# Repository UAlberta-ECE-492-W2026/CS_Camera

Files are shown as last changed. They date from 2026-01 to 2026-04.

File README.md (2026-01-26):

# Compressed Sensing Camera

## Project Overview
The objective of this capstone project is to design and build a functional prototype camera using compressed sensing principles with a single-pixel sensor to capture visible light. The system will acquire compressed measurements and reconstruct images using computational algorithms, demonstrating the viability of sub-Nyquist sampling for image acquisition.

## Team Members
- **[Mazen]** - [Role/Responsibility]
- **[Omar]** - [Role/Responsibility]
- **[Cole]** - [Role/Responsibility]
- **[Ghassan]** - [Role/Responsibility]

**Supervisor:** Steven Knudsen 
**Course:** ECE 492 - Capstone Design Project  
**Institution:** University of Alberta  
**Term:** Winter 2026

## Project Goals
- Design and implement hardware for single-pixel compressed sensing camera
- Develop firmware for measurement acquisition and control
- Implement image reconstruction algorithms (e.g., basis pursuit, greedy algorithms)
- Validate system performance through experimental testing
- Deliver a working prototype with documentation

## System Architecture
The system consists of three main components:
1. **Optical Frontend** - Single-pixel detector, spatial light modulator/DMD, optics
2. **Embedded System** - Microcontroller-based data acquisition and control
3. **Reconstruction Backend** - PC-based image processing and reconstruction

## Repository Structure
```
CS_Camera/
├── Firmware/              # Embedded firmware for sensor control and data acquisition
├── Image_reconstruction/  # Image reconstruction algorithms and processing code
├── docs/                  # Design documents, reports, and presentations
├── hardware/             # Schematics, PCB files, and hardware documentation
├── tests/                # Test scripts and validation data
├── data/                 # Sample measurements and calibration files
└── README.md             # This file
```

## Getting Started

### Prerequisites
**Hardware:**
- 
- Development board: Pi 
- Single-pixel detector: 
- LCD:

**Software:**
- TODO

### Installation
```bash
# Clone the repository
git clone git@github.com:UAlberta-ECE-492-W2026/CS_Camera.git
cd CS_Camera

# Setup firmware development environment
cd Firmware

```

### Quick Start
TODO

## Development Workflow
- **Branch Strategy:** Feature branches off `main`, merge via pull requests
- **Code Review:** All PRs require at least two review before merging
- **Testing:** Run tests before committing changes
- **Documentation:** Update relevant docs with any architectural changes

## Documentation

- Design specifications
- Hardware schematics
- Algorithm descriptions
- Testing procedures
- Final report and presentations

## Current Status/Milestones
- [ ] Project planning and requirements definition
- [ ] Hardware design and component selection
- [ ] Firmware development
- [ ] Image reconstruction algorithm implementation
- [ ] System integration and testing
- [ ] Final documentation and presentation

**Last Updated:** January 26, 2026

## Acknowledgments
Special thanks to the University of Alberta ECE Department and our project supervisor for their support and guidance.

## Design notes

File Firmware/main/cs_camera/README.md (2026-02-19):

# CS Camera - Modular Firmware Structure

## Project Structure

```
Firmware/main/
├── main.c                       # Main entry point
├── CMakeLists.txt              # Root build configuration
├── pico_sdk_import.cmake       # Pico SDK import
│
├── modules/
│   ├── storage/                # SD Card Module
│   │   ├── sd_storage.h        # Storage API
│   │   ├── sd_storage.c        # Storage implementation
│   │   ├── hw_config.h         # SD card hardware config
│   │   ├── hw_config.c
│   │   └── CMakeLists.txt      # Builds 'storage' library
│   │
│   ├── sensor/                 # Photodiode/ADC Module
│   │   ├── photodiode.h        # Sensor API
│   │   ├── photodiode.c        # Sensor implementation
│   │   └── CMakeLists.txt      # Builds 'sensor' library
│   │
│   └── display/                # LCD Display Module
│       ├── lcd_driver.h        # Display API
│       ├── lcd_driver.c        # Display implementation (stub)
│       └── CMakeLists.txt      # Builds 'display' library
│
└── ../lib/
    └── no-OS-FatFS/            # External FatFS library (shared)
```

## How It Works

### Single Project, Multiple Modules
- **One** Pico project with **one** root `CMakeLists.txt`
- Each module is a **library** (not a separate project)
- All modules compile together into **one** `.uf2` file

### Module Independence
- **Storage**: Handles SD card, file system, data logging
- **Sensor**: Handles photodiode ADC sampling
- **Display**: Handles LCD graphics and rendering
- **Main**: Coordinates all modules, implements application logic

### Clean Interfaces
Each module exposes a simple API:
- `module_init()` - Initialize the module
- `module_*()` - Module-specific functions
- Modules don't depend on each other

## Building the Project

### Using VS Code Pico Extension

1. **Open the main folder** in VS Code:
   - File → Open Folder → Select `Firmware/main/`

2. **Configure the project**:
   - Pico extension should detect the project automatically
   - Select Pico2 board if prompted

3. **Compile**:
   - Click "Compile" in the Pico extension
   - Or use CMake Tools extension

4. **Flash to Pico**:
   - Hold BOOTSEL button, connect Pico
   - Copy `build/cs_camera.uf2` to the Pico drive

### Manual Build

```bash
cd Firmware/main
mkdir build
cd build
cmake ..
make
```

## Module APIs

### Storage Module
```c
#include "modules/storage/sd_storage.h"

bool storage_init(void);
int storage_write_file(const char *filename, const void *data, uint32_t size);
int storage_append_file(const char *filename, const void *data, uint32_t size);
```

### Sensor Module
```c
#include "modules/sensor/photodiode.h"

bool sensor_init(void);
uint16_t sensor_read_sample(void);
uint16_t sensor_read_voltage_mv(void);
```

### Display Module
```c
#include "modules/display/lcd_driver.h"

bool display_init(void);
void display_clear(uint16_t color);
void display_text(uint16_t x, uint16_t y, const char *text, uint16_t color);
```

## Next Steps

### Display Module
The display module is currently a **stub**. To implement:
1. Determine your LCD type (ST7735, ILI9341, etc.)
2. Add LCD driver library or implement SPI communication
3. Update `lcd_driver.c` with actual initialization and drawing

### Sensor Module
- Currently implements basic ADC reading
- TODO: Add DMA-based continuous sampling
- TODO: Add data buffering for high-speed acquisition

### Storage Module
- Fully functional for basic file operations
- Tested with FatFS library
- Ready for data logging

## Pin Configuration

### SD Card (SPI1)
- GPIO 10: SCK
- GPIO 11: MOSI
- GPIO 12: MISO
- GPIO 13: CS

### Photodiode
- GPIO 26: ADC0 (Analog input)

### LCD (To be configured)
- TBD based on your LCD module

## Adding New Modules

1. Create folder: `modules/new_module/`
2. Create files: `new_module.h`, `new_module.c`, `CMakeLists.txt`
3. In module `CMakeLists.txt`:
   ```cmake
   add_library(new_module STATIC new_module.c)
   target_include_directories(new_module PUBLIC ${CMAKE_CURRENT_LIST_DIR})
   target_link_libraries(new_module pico_stdlib)
   ```
4. In root `CMakeLists.txt`:
   ```cmake
   add_subdirectory(modules/new_module)
   target_link_libraries(cs_camera new_module)
   ```

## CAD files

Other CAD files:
hardware/Fusion/Lens D-Cx Dia38mm FL50mm.f3d
hardware/Fusion/SD Card Reader (Assembly).f3z

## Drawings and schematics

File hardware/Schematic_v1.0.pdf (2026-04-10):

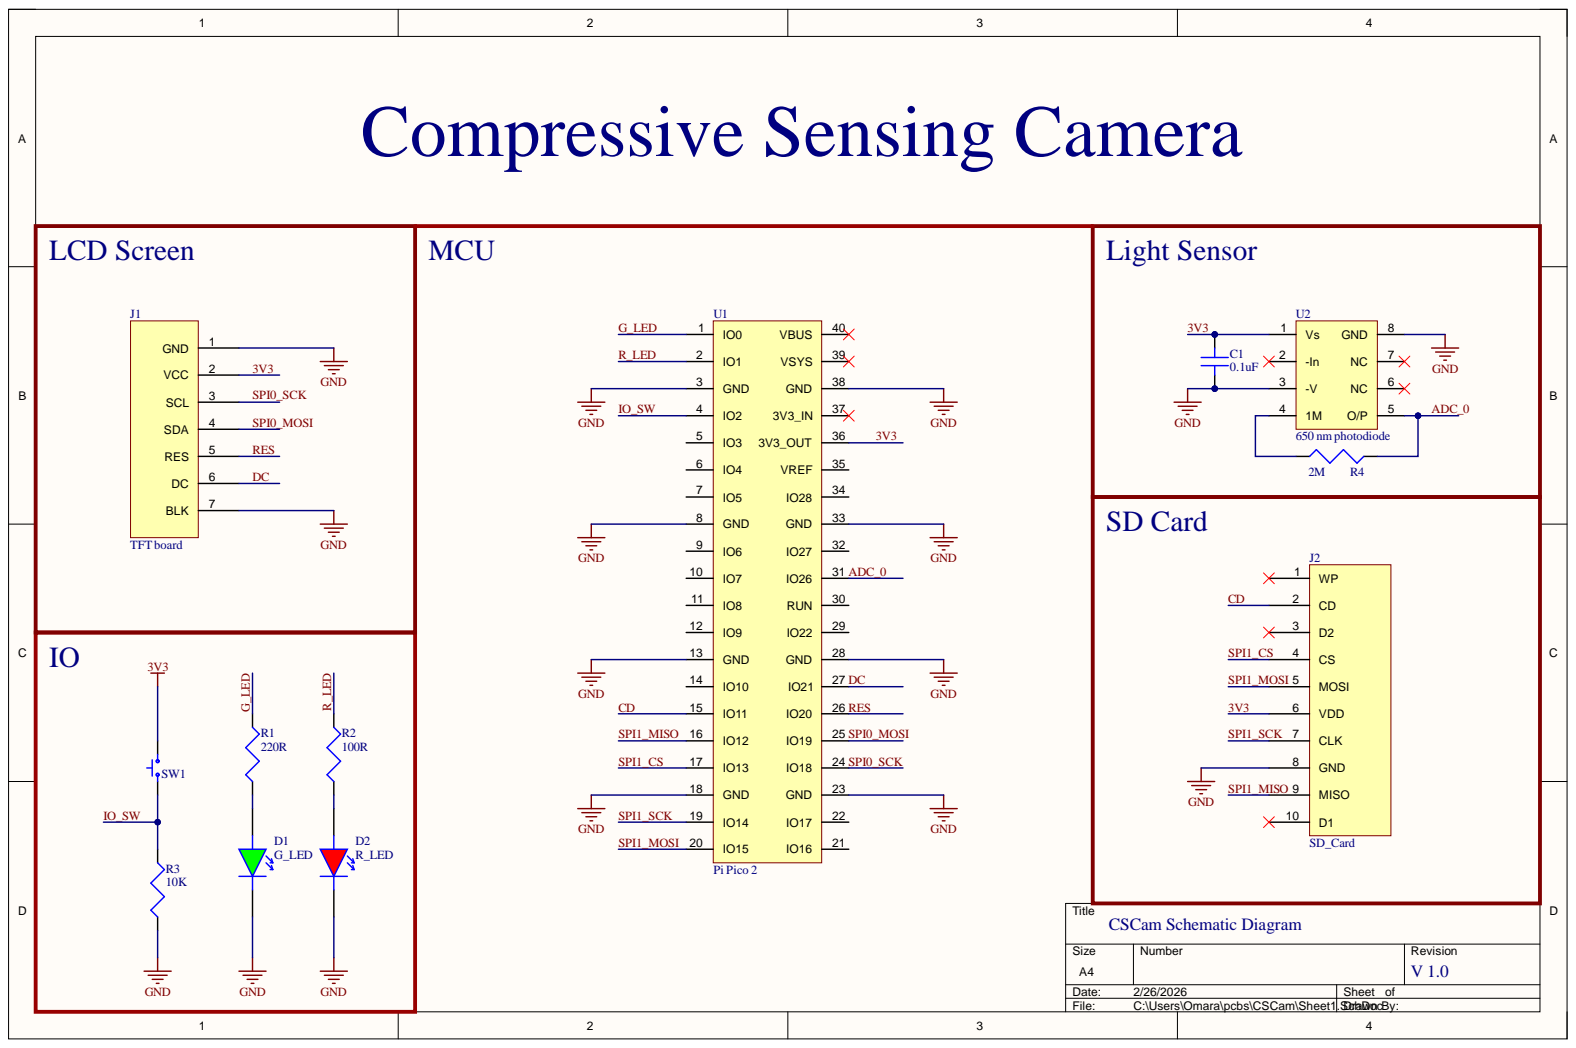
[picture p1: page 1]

S i z e A 4 | Number | Rev i s i o n V 1.0

Date: 2/26/2026 | Sheet of
F i le: C:\User s\Omara\pcbs\CSCam\Sheet1.SDrchDoc awn B | y :

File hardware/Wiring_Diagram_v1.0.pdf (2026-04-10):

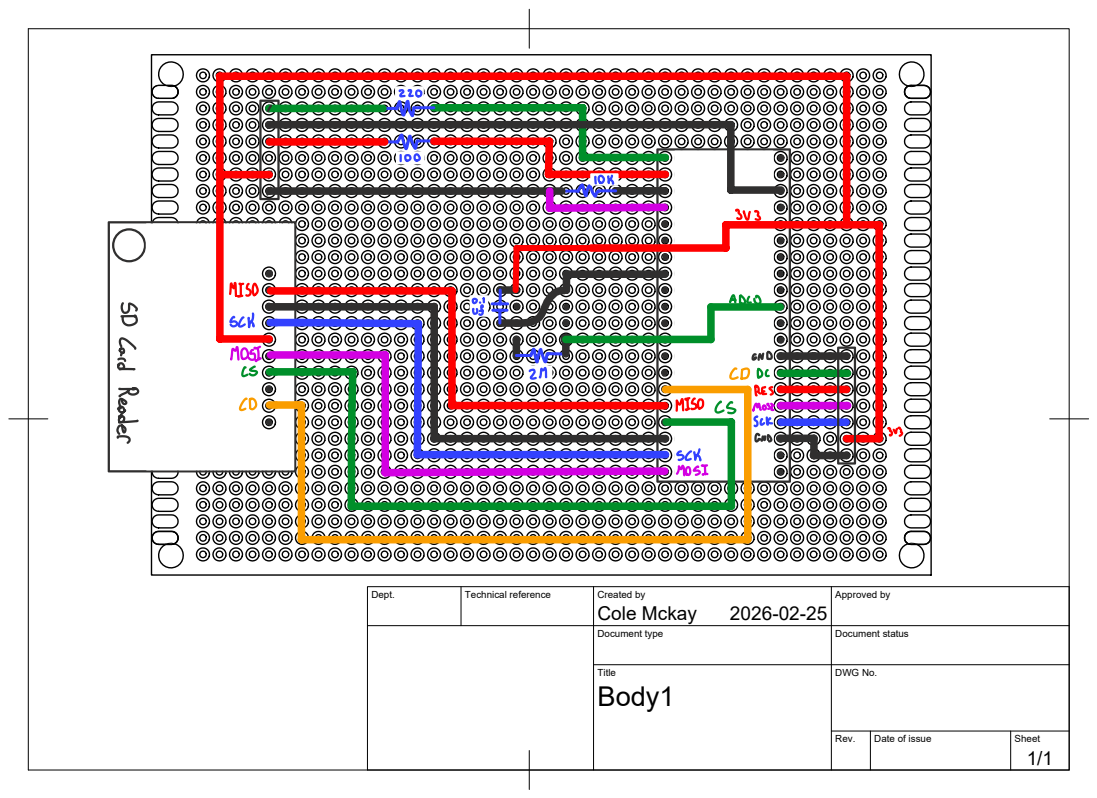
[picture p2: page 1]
Dept.; Technical reference; Created by; Approved by; Document type; Document status; Title; DWG No.; Rev.; Date of issue; Sheet; Body1; Cole Mckay

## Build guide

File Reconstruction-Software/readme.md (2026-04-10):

# Compressive Sensing Camera — MATLAB Reconstruction Software

**Author:** Cole Mckay (cdmckay1@ualberta.ca)  
**Capstone Project — University of Alberta**

---

## Table of Contents

1. [Project Overview](#1-project-overview)
2. [Repository Structure](#2-repository-structure)
3. [Mathematical Background](#3-mathematical-background)
   - [3.1 Walsh-Hadamard Basis & Compressive Sensing](#31-walsh-hadamard-basis--compressive-sensing)
   - [3.2 Simple Back-Projection Reconstruction](#32-simple-back-projection-reconstruction)
   - [3.3 Edge-Preserving Total Variation Reconstruction](#33-edge-preserving-total-variation-reconstruction)
4. [CNN Enhancement Architecture](#4-cnn-enhancement-architecture)
   - [4.1 Motivation](#41-motivation)
   - [4.2 Network Architecture (ResNet-style)](#42-network-architecture-resnet-style)
   - [4.3 Training Pipeline](#43-training-pipeline)
5. [Camera Emulation](#5-camera-emulation)
6. [MATLAB Apps](#6-matlab-apps)
7. [Configuration](#7-configuration)
8. [Getting Started](#8-getting-started)
9. [Dependencies](#9-dependencies)

---

## 1. Project Overview

This repository folder contains the MATLAB software layer for a **single-pixel compressive sensing (CS) camera** capstone project. Rather than capturing a full image on a conventional sensor array, the hardware captures a scene through a sequence of structured **Walsh-Hadamard binary masks** and records a single scalar measurement (ADC value) per mask. The software then reconstructs a full 2D image from this heavily undersampled measurement set using one of three algorithms:

| Algorithm | Speed | Quality | Notes |
|---|---|---|---|
| Simple Back-Projection | Fast | Moderate | Linear; good baseline |
| Total Variation (TV) | Slow | High | Edge-preserving, iterative |
| CNN Enhancement | Fast (inference) | Highest | Requires pre-trained model |

---

## 2. Repository Structure

```
project_root/
│
├── +reco/                          # Reconstruction algorithms
│   ├── simpleReconstruction.m      # Linear back-projection
│   ├── tvReconstruction.m          # TV-minimization solver
│   └── cnnReconstruction.m         # CNN-enhanced reconstruction
│
├── +utils/                         # Core utility functions
│   ├── emulateCameraCapture.m      # Hardware emulation
│   ├── generateWalshMask.m         # Walsh-Hadamard mask generation
│   ├── getOptimalCore.m            # Optimal low-frequency mask selection
│   ├── loadConfig.m                # JSON config loader
│   ├── selectMaskIndexes.m         # Sampling strategy selector
│   └── simulateCapture.m          # ADC capture simulation
│
├── +models/                        # Trained CNN model files (.mat)
│   ├── cs_enhancement_net_ResNet.mat
│   └── cs_enhancement_net_ResNet_50p.mat
│
├── +tools/                         # Standalone scripts & tools
│   ├── train_CS_Enhancement_CNN.m  # CNN training script
│   ├── test_emulateCameraCapture.m # Integration test
│   ├── generate_training_data.m    # Dataset generation
│   └── ...
│
├── configs/
│   └── camera_settings.json        # Resolution, sampling %, noise params
│
├── data/                           # Training datasets and capture CSVs
├── images/                         # Test images (BSDS300, tiny-imagenet)
├── mask_firmware/                  # Embedded C++ mask generator for hardware
│   ├── main.cpp
│   ├── WalshMaskGenerator.cpp
│   └── WalshMaskGenerator.h
│
├── assets/
│   └── eng_logo.png
│
├── Emulation_app.mlapp             # MATLAB App: camera emulation UI
└── Reconstruction_app.mlapp        # MATLAB App: reconstruction UI
```

---

## 3. Mathematical Background

### 3.1 Walsh-Hadamard Basis & Compressive Sensing

The system measures a scene $\mathbf{x} \in \mathbb{R}^{N}$ (a vectorized $\sqrt{N} \times \sqrt{N}$ image) using $M \ll N$ linear measurements. Each measurement $y_i$ is the inner product of the scene with a binary Walsh-Hadamard mask $\mathbf{\phi}_i \in \{0, 1\}^N$:

$$y_i = \mathbf{\phi}_i^T \mathbf{x} + \eta_i, \quad i = 1, \ldots, M$$

where $\eta_i$ is additive noise. Stacking all measurements:

$$\mathbf{y} = \mathbf{\Phi} \mathbf{x} + \mathbf{\eta}$$

where $\mathbf{\Phi} \in \mathbb{R}^{M \times N}$ is the **sensing matrix**, with each row being a flattened Walsh mask. Because Walsh-Hadamard functions form an orthonormal basis ordered by **sequency** (the number of zero-crossings, analogous to frequency), the system preferentially captures low-sequency masks — which carry the most image energy — enabling meaningful reconstruction even at aggressive undersampling ratios (e.g., 50%).

A DC baseline is removed before reconstruction to center the measurements:

$$\mathbf{y}_{AC} = \mathbf{y} - \bar{y}\mathbf{1}$$

---

### 3.2 Simple Back-Projection Reconstruction

The simplest reconstruction is a **linear back-projection** (pseudo-inverse approximation):

$$\hat{\mathbf{x}} = \mathbf{\Phi}^T \mathbf{y}_{AC}$$

In practice, this is computed mask-by-mask without explicitly forming $\mathbf{\Phi}$:

$$\hat{\mathbf{x}} = \sum_{i=1}^{M} y_{AC,i} \cdot \mathbf{\phi}_i$$

Each Walsh mask is weighted by its AC measurement value and accumulated into the image. The result is normalized to $[0, 1]$:

$$\hat{x}_{norm} = \frac{\hat{\mathbf{x}} - \min(\hat{\mathbf{x}})}{\max(\hat{\mathbf{x}}) - \min(\hat{\mathbf{x}})}$$

**Complexity:** $O(M \cdot N)$ — fast, but produces visible Walsh-Hadamard ringing artifacts at low sampling rates because the unmeasured basis components implicitly contribute zero energy.

> **Implemented in:** `+reco/simpleReconstruction.m`

---

### 3.3 Edge-Preserving Total Variation Reconstruction

To suppress ringing artifacts while preserving sharp edges, the system solves a **Total Variation (TV) minimization** problem:

$$\hat{\mathbf{x}} = \arg\min_{\mathbf{x}} \underbrace{\|\mathbf{\Phi}\mathbf{x} - \mathbf{y}\|_2^2}_{\text{data fidelity}} + \lambda \underbrace{\text{TV}_w(\mathbf{x})}_{\text{regularization}}$$

where $\lambda$ is a regularization weight (set to 50 in the current configuration).

#### Isotropic TV with Perona-Malik Edge Weighting

Standard isotropic TV uses the image gradient magnitude:

$$\text{TV}(\mathbf{x}) = \sum_{p} \sqrt{(\nabla_x \mathbf{x}_p)^2 + (\nabla_y \mathbf{x}_p)^2}$$

This implementation extends TV with **Perona-Malik edge weights** $w_p$ to be less penalizing at strong edges:

$$w_p = \frac{1}{1 + \left(\|\nabla \mathbf{x}_p\| / \sigma\right)^2}$$

where $\sigma$ is an adaptive edge-stopping threshold set to $0.25 \cdot \max(|\mathbf{y}|)$. The weighted TV gradient (used in the gradient descent update) becomes the divergence of the weighted normalized gradient field:

$$\nabla_\mathbf{x} \text{TV}_w = -\text{div}\left( w_p \cdot \frac{\nabla \mathbf{x}}{\|\nabla \mathbf{x}\| + \epsilon} \right)$$

where $\epsilon = 10^{-5}$ prevents division by zero.

#### Gradient Descent Solver

The full gradient descent update at iteration $k$ is:

$$\mathbf{x}^{(k+1)} = \mathbf{x}^{(k)} - \alpha \left[ \mathbf{\Phi}^T(\mathbf{\Phi}\mathbf{x}^{(k)} - \mathbf{y}) + \lambda \nabla_\mathbf{x} \text{TV}_w(\mathbf{x}^{(k)}) \right]$$

The step size $\alpha$ is set using the **Lipschitz-stable** rule:

$$\alpha = \frac{1.9}{\|\mathbf{\Phi}\|_2^2}$$

The solver runs for 300 iterations, printing progress every 50. The initial state is seeded with the linear back-projection $\mathbf{x}^{(0)} = \mathbf{\Phi}^T \mathbf{y}_{AC}$.

> **Implemented in:** `+reco/tvReconstruction.m`

---

## 4. CNN Enhancement Architecture

### 4.1 Motivation

The simple back-projection reconstruction is fast but suffers from structured **Walsh-Hadamard artifacts** — a characteristic checkerboard-like pattern caused by the abrupt truncation of the measurement basis. Rather than solving an expensive iterative optimization at inference time, a **residual convolutional neural network** learns a mapping from the noisy back-projection to the ground-truth image, effectively learning to suppress exactly the artifact pattern produced by this sensing system.

### 4.2 Network Architecture (ResNet-style)

The network is a lightweight **residual (skip-connection) CNN** that learns the *artifact residual* rather than the full image mapping. This is motivated by the observation that the back-projection $\hat{\mathbf{x}}$ already contains the correct low-frequency image content — only the high-frequency artifact component needs to be estimated and removed.

```
Input (N×N×1)
    │
    ├────────────────────────────────── Skip Connection ──────────────────────┐
    │                                                                          │
    ▼                                                                          │
Conv2D (5×5, 64 filters) → ReLU                  ← Artifact extraction       │
    ▼                                                                          │
Conv2D (3×3, 32 filters) → ReLU                  ← Artifact refinement       │
    ▼                                                                          │
Conv2D (5×5, 1 filter)                            ← Artifact map              │
    │                                                                          │
    └───────────────────────────────────► Addition ◄──────────────────────────┘
                                              │
                                              ▼
                                    Enhanced Output (N×N×1)
                                              │
                                              ▼
                                    Regression Loss (MSE)
```

The network learns artifact weights $\mathbf{r}$ such that:

$$\hat{\mathbf{x}}_{enhanced} = \hat{\mathbf{x}}_{simple} + f_{CNN}(\hat{\mathbf{x}}_{simple}; \mathbf{\theta})$$

where $f_{CNN}$ is the residual branch. At inference, this is equivalent to the network predicting the ground truth directly via the identity shortcut.

**Layer details:**

| Layer | Kernel | Filters | Activation | Role |
|---|---|---|---|---|
| Conv1 | 5×5 | 64 | ReLU | Patch feature extraction |
| Conv2 | 3×3 | 32 | ReLU | Non-linear mapping |
| Conv3 | 5×5 | 1 | — | Residual artifact map |
| Addition | — | — | — | Skip + residual |

All convolutions use `'same'` padding to preserve spatial dimensions throughout.

### 4.3 Training Pipeline

> **Script:** `+tools/train_CS_Enhancement_CNN.m`

**Data Preparation:**

1. Raw ADC measurements $\mathbf{y}$ are loaded from `cnn_training_data_50p.mat`
2. The sensing matrix $\mathbf{\Phi}$ is built from the mask list
3. For each training sample, a simple back-projection is computed and normalized to produce $\hat{\mathbf{x}}^{(i)}_{simple}$ — this is the **network input**
4. The ground-truth cropped/resized image is the **network target**

**Training Configuration:**

| Parameter | Value |
|---|---|
| Optimizer | Adam |
| Initial Learning Rate | $10^{-3}$ |
| Max Epochs | 50 |
| Mini-batch Size | 64 |
| Shuffle | Every epoch |
| Execution | GPU (CUDA) |
| Loss | MSE (Regression) |
| Training Data | BSDS300 + tiny-imagenet @ 50% sampling |

**Trained model output:** `+models/cs_enhancement_net_ResNet_50p.mat`

The model is loaded **once** at first call using a `persistent` variable in `cnnReconstruction.m` to avoid repeated disk reads during a session.

---

## 5. Camera Emulation

> **Function:** `+utils/emulateCameraCapture.m`

The emulation pipeline mirrors the physical hardware capture process:

1. **Load image** — accepts a filepath or raw matrix
2. **Greyscale conversion** — colour images are converted via `im2gray`
3. **Square crop** — a centred square crop is taken using `centerCropWindow2d` to match the aspect ratio of the hardware aperture
4. **Resize** — the crop is resized to the target resolution defined in `camera_settings.json`
5. **Simulate capture** — `utils.simulateCapture` projects the image through each Walsh mask, optionally adding noise to emulate ADC quantization and photon shot noise

**Output format:** an $N \times 2$ matrix where column 1 is the mask index and column 2 is the ADC value. A header row with index $-1$ encodes the image resolution for downstream parsers.

---

## 6. MATLAB Apps

Two MATLAB App Designer GUIs are provided:

| App | File | Purpose |
|---|---|---|
| **Emulation App** | `Emulation_app.mlapp` | Load an image, select sampling %, run emulated capture, export data |
| **Reconstruction App** | `Reconstruction_app.mlapp` | Import capture CSV, choose reconstruction algorithm, display result |

---

## 7. Configuration

All camera and sampling parameters are stored in `configs/camera_settings.json`:

```json
{
    "hardware": {
        "adc_bits": 12,
        "v_ref": 3.3,
        "quantization_levels": 4096,
        "saturation_limit": 3800
    },
    "sampling_parameters": {
        "resolution": [64, 64],
        "samples_per_mask": 256,
        "sampling_pct": 0.25,
        "core_mask_count": 1024
    },
    "bias_profile": {
        "low_freq_bias_pct": 0.15
    },
    "sensor_noise": {
        "std_dev_counts": 2.5,
        "dark_current_counts": 12.0
    },
    "mask_constraints": {
        "black_leakage_pct": 0.01,
        "white_attenuation_pct": 1.0
    }
}
```

**Hardware**

| Field | Value | Description |
|---|---|---|
| `adc_bits` | 12 | ADC resolution |
| `v_ref` | 3.3 V | ADC reference voltage |
| `quantization_levels` | 4096 | Total ADC levels ($2^{12}$) |
| `saturation_limit` | 3800 | Clipping threshold (counts) |

**Sampling Parameters**

| Field | Value | Description |
|---|---|---|
| `resolution` | `[64, 64]` | Square image dimensions |
| `samples_per_mask` | 256 | ADC readings averaged per mask exposure |
| `sampling_pct` | 0.25 | Fraction of $N^2$ masks captured (25%) |
| `core_mask_count` | 1024 | Lowest-sequency masks always included |

**Noise & Mask Constraints**

| Field | Value | Description |
|---|---|---|
| `std_dev_counts` | 2.5 | Gaussian read noise (ADC counts) |
| `dark_current_counts` | 12.0 | Dark current offset (ADC counts) |
| `low_freq_bias_pct` | 0.15 | Extra sampling weight on low-sequency masks |
| `black_leakage_pct` | 0.01 | Light leakage through nominally black mask pixels |
| `white_attenuation_pct` | 1.0 | Transmission loss through white mask pixels |

---

## 8. Getting Started

### Running a reconstruction from a CSV export

```matlab
cfg = utils.loadConfig('configs/camera_settings.json');
dataMatrix = readmatrix('data/camera_data_export.csv');

% Simple back-projection
img_simple = reco.simpleReconstruction(dataMatrix);
imshow(img_simple); title('Simple Reconstruction');

% Total Variation
img_tv = reco.tvReconstruction(dataMatrix);
imshow(img_tv); title('TV Reconstruction');

% CNN-Enhanced
img_cnn = reco.cnnReconstruction(dataMatrix);
imshow(img_cnn); title('CNN Enhanced');
```

### Running the emulator test

```matlab
run('+tools/test_emulateCameraCapture.m')
```

### Training the CNN

```matlab
% Requires cnn_training_data_50p.mat in /data
run('+tools/train_CS_Enhancement_CNN.m')
```

---

## 9. Dependencies

| Requirement | Notes |
|---|---|
| MATLAB R2021b+ | Core language |
| Deep Learning Toolbox | `trainNetwork`, `predict`, layer definitions |
| Image Processing Toolbox | `im2gray`, `imresize`, `centerCropWindow2d` |
| Parallel Computing Toolbox | GPU training (`ExecutionEnvironment: 'gpu'`) |
| CUDA-capable GPU | Recommended for training; inference runs on CPU |

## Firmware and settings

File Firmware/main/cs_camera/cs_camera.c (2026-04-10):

#include <stdio.h>
#include <string.h>
#include <stdlib.h>
#include "pico/stdlib.h"
#include "pico/rand.h"
// #include "pico/gpio.h"
#include "photodiode.h"
#include "lcd_controller.h"
#include "sd_storage.h"
#include "WalshMaskGenerator.h"
#include "ff.h"

#define MASK_NUM        1024
#define BUTTON_PIN      2  // GPIO pin connected to Button output
#define NUM_READINGS    500 // READING PER MASK (e.g., 10 readings per mask)
#define DELAY_MS        100
#define HEADERSIZE      1  // For example, if we want to store a header in the file (e.g., timestamp, mask info, etc.)

#define MASK_WIDTH      64
#define MASK_HEIGHT     64

#define LCD_WIDTH       240
#define LCD_HEIGHT      240

#define COLOR_BLACK     0x0000
#define COLOR_WHITE     0xFFFF

#define LINE_LENGTH     12 // max csv line length ("32767,32767\n")

#define GREEN_LED_PIN   0
#define RED_LED_PIN     1

#define NUM_IMP_INDICES 256
const uint16_t important_indices[NUM_IMP_INDICES] = {
    0, 1, 2, 3, 4, 5, 6, 7, 8, 9, 10, 11, 12, 13, 14, 15, 16, 17, 18, 19, 20, 
    21, 22, 64, 65, 66, 67, 68, 69, 70, 71, 72, 73, 74, 75, 76, 77, 78, 79, 80, 
    81, 82, 83, 84, 85, 128, 129, 130, 131, 132, 133, 134, 135, 136, 137, 138, 
    139, 140, 141, 142, 143, 144, 145, 146, 147, 148, 192, 193, 194, 195, 196, 
    197, 198, 199, 200, 201, 202, 203, 204, 205, 206, 207, 208, 209, 210, 256, 
    257, 258, 259, 260, 261, 262, 263, 264, 265, 266, 267, 268, 269, 270, 271, 
    272, 273, 320, 321, 322, 323, 324, 325, 326, 327, 328, 329, 330, 331, 332, 
    333, 334, 335, 336, 384, 385, 386, 387, 388, 389, 390, 391, 392, 393, 394, 
    395, 396, 397, 398, 399, 448, 449, 450, 451, 452, 453, 454, 455, 456, 457, 
    458, 459, 460, 461, 462, 512, 513, 514, 515, 516, 517, 518, 519, 520, 521, 
    522, 523, 524, 525, 576, 577, 578, 579, 580, 581, 582, 583, 584, 585, 586, 
    587, 588, 640, 641, 642, 643, 644, 645, 646, 647, 648, 649, 650, 651, 704, 
    705, 706, 707, 708, 709, 710, 711, 712, 713, 714, 768, 769, 770, 771, 772, 
    773, 774, 775, 776, 777, 832, 833, 834, 835, 836, 837, 838, 839, 840, 896, 
    897, 898, 899, 900, 901, 902, 903, 960, 961, 962, 963, 964, 965, 966, 1024, 
    1025, 1026, 1027, 1028, 1029, 1088, 1089, 1090, 1091, 1092, 1152, 1153, 1154, 
    1155, 1216, 1217, 1218, 1280, 1281, 1344
};

#define NORMALIZATION   2048
static uint16_t black_val = 0;
static uint16_t white_val = 0;

/**
 * Initialize the TTP223 capacitive touch sensor
 */
void button_init(void) {
    gpio_init(BUTTON_PIN);
    gpio_set_dir(BUTTON_PIN, GPIO_IN);  // Set as input
    printf("TTP223 initialized on GPIO %d\n", BUTTON_PIN);
}

/**
 * Check if TTP223 is pressed (button output is HIGH)
 * @return true if button is pressed, 0 otherwise
 */
bool button_is_pressed(void) {
    return gpio_get(BUTTON_PIN);
}

/**
 * Wait for TTP223 button press with optional timeout
 * This function blocks until the button is pressed
 */
void button_wait_for_press(void) {
    gpio_put(RED_LED_PIN, false);
    bool red_on = false;
    bool sd_present = false;

    printf("Waiting for TTP223 button press to start capture...\n");

    uint8_t counter = 0;
    while (!button_is_pressed() || !sd_present) {
        sd_present = !gpio_get(CD_PIN);
        counter = (counter + 1) % 10;
        if(counter == 0){
            red_on = !red_on;
        }

        gpio_put(RED_LED_PIN, red_on && !sd_present);
        gpio_put(GREEN_LED_PIN, sd_present);
        sleep_ms(50);  // Check every 50ms
    }
    sleep_ms(100);  // Debounce delay
    printf("Button pressed! Starting capture sequence...\n");
}

/**
 * a calibration sequence that updates our black and white values used for
 * data preprocessing and normalization
 */
void calibrate(void) {
    display_fill(COLOR_BLACK);
    sleep_ms(DELAY_MS);
    uint32_t average_reading = 0;
    for (int i = 0; i < NUM_READINGS; i++) {
        average_reading += sensor_read_sample();
        sleep_us(50);
    }
    average_reading /= NUM_READINGS;
    black_val = (uint16_t) average_reading;

    display_fill(COLOR_WHITE);
    sleep_ms(DELAY_MS);
    average_reading = 0;
    for (int i = 0; i < NUM_READINGS; i++) {
        average_reading += sensor_read_sample();
        sleep_us(50);
    }
    average_reading /= NUM_READINGS;
    white_val = (uint16_t) average_reading;
}

bool get_next_filename(char *out, size_t out_size, const char *prefix, const char *ext);

int main()
{
    // INITIALIZATION
    stdio_init_all();

    gpio_init(GREEN_LED_PIN);
    gpio_init(RED_LED_PIN);
    gpio_init(CD_PIN);
    
    gpio_set_dir(GREEN_LED_PIN, true);
    gpio_set_dir(RED_LED_PIN, true);
    gpio_set_dir(CD_PIN, GPIO_IN);
    
    gpio_put(GREEN_LED_PIN, false);
    gpio_put(RED_LED_PIN, true);
    gpio_pull_up(CD_PIN);

    while(true) {

        gpio_put(RED_LED_PIN, true);

        // Initialize TTP223 button
        button_init();

        if (!display_init()) {
            printf("Failed to initialize display\n");
            return 1;
        }

        if (!sensor_init()) {
            printf("Failed to initialize sensor\n");
            return 1;
        }

        // INITIALIZE BUFFERS FOR SENSOR READINGS AND MASKS
        uint16_t sensor_buffer[HEADERSIZE + MASK_NUM] = {0};
        int16_t mask_indices[HEADERSIZE + MASK_NUM] = {0};
        uint8_t mask_buffer[MASK_HEIGHT * MASK_WIDTH] = {0};
        uint16_t mask_index = 0;

        sensor_buffer[0] = 64;
        mask_indices[0] = -1;

        gpio_put(RED_LED_PIN, false);
        gpio_put(GREEN_LED_PIN, true);

        // WAIT FOR TTP223 BUTTON PRESS TO START CAPTURE SEQUENCE
        button_wait_for_press();
        
        // BUTTON PRESS: START CAPTURE SEQUENCE
        // GREEN LED ON TO INDICATE CAPTURE STARTED
        printf("starting...\n");

        gpio_put(GREEN_LED_PIN, true);
        gpio_put(RED_LED_PIN, false);

        // ----- Fisher-Yates shuffle to generate random, non-repeating sequence -----
        printf("starting shuffle...");
        static uint16_t all_indices[MASK_WIDTH * MASK_HEIGHT];
        for (uint16_t i = 0; i < MASK_WIDTH * MASK_HEIGHT; i++) {
            all_indices[i] = i;
        }

        // ----- Guarantee inclusion of important indices -----
        for(uint16_t i = 0; i < NUM_IMP_INDICES; i++) {
            uint16_t start = all_indices[i];
            uint16_t target = all_indices[important_indices[i]];

            all_indices[i] = target;
            all_indices[important_indices[i]] = start;
        }
        // ----- Guarantee inclusion of important indices -----
        
        for (uint16_t i = MASK_WIDTH * MASK_HEIGHT - 1; i > NUM_IMP_INDICES; i--) {
            // j must not land in the protected zone [0, NUM_IMP_INDICES)
            uint16_t j = NUM_IMP_INDICES + get_rand_32() % (i + 1 - NUM_IMP_INDICES);
            
            // swap the two elements
            uint16_t temp = all_indices[i];
            all_indices[i] = all_indices[j];
            all_indices[j] = temp;
        }
        printf(" Done!\n");
        // ----- Fisher-Yates shuffle to generate random, non-repeating sequence -----

        // ----- Take readings and save them into buffer -----
        for (int i = HEADERSIZE; i < MASK_NUM + HEADERSIZE; i++)
        {
            if(i % 10 == 0) {
                calibrate();
            }

            // STEP 1: DISPLAY MASK NUMBER ON LCD
            mask_index = all_indices[i];
            generate_walsh_mask(mask_index, MASK_WIDTH, MASK_HEIGHT, mask_buffer);
            display_show_mask(mask_buffer, MASK_WIDTH, MASK_HEIGHT);
            
            // STEP 2: WAIT FOR SOME TIME FOR THE MASK TO BE DISPLAYED
            sleep_ms(DELAY_MS);
            
            // STEP 3: CAPTURE SENSOR READINGS
            uint32_t average_reading = 0;
            for (int j = 0; j < NUM_READINGS; j++) {
                average_reading += sensor_read_sample();
                sleep_us(50);
            }

            uint32_t range = white_val - black_val;
            uint32_t floored = (average_reading < black_val) ? 0 : average_reading - black_val;
            uint16_t calibrated_reading = (uint16_t)((floored * NORMALIZATION) / range);
            
            sensor_buffer[i] = calibrated_reading;

            mask_indices[i] = mask_index;

            printf("%d. measuring mask %d: %d\n", i, mask_index, calibrated_reading);

            if(i % 5 == 0) {
                gpio_put(GREEN_LED_PIN, i % 10 == 0);
            }
        }
        // ----- Take readings and save them into buffer -----

        // ----- Save data into csv on the SD card -----
        char csv_data[(MASK_NUM + HEADERSIZE) * (LINE_LENGTH)];
        size_t data_size = 0;

        for (uint16_t i = 0; i < MASK_NUM + HEADERSIZE; i++) {
            data_size += snprintf(csv_data + data_size, sizeof(csv_data) - data_size, 
                                    "%d,%d\n", mask_indices[i], sensor_buffer[i]);
        }

        sd_storage_init();
        // WRITE BUFFER TO SD CARD
        char filename[32];
        get_next_filename(filename, sizeof(filename), "photo", "csv");
        if (sd_write_file(filename, csv_data, data_size)) {
            printf("Successfully wrote sensor data to SD card: %s (%zu bytes)\n", filename, data_size);
        } else {
            printf("Failed to write sensor data to SD card\n");
        }
        // ----- Save data into csv on the SD card -----

        gpio_put(GREEN_LED_PIN, true);
        gpio_put(RED_LED_PIN, false);

        // DEINITIALIZE SD STORAGE
        sd_storage_deinit();
    }
}

bool get_next_filename(char *out, size_t out_size, const char *prefix, const char *ext) {
    DIR dir;
    FILINFO fno;

    FRESULT res = f_opendir(&dir, "0:/");
    if (res != FR_OK) {
        snprintf(out, out_size, "%s1.%s", prefix, ext);
        return false;
    }

    int max_index = 0;
    size_t prefix_len = strlen(prefix);

    while (f_readdir(&dir, &fno) == FR_OK && fno.fname[0] != '\0') {
        // Check prefix matches
        if (strncmp(fno.fname, prefix, prefix_len) != 0)
            continue;

        // Check extension matches
        char *dot = strrchr(fno.fname, '.');
        if (!dot || strcmp(dot + 1, ext) != 0)
            continue;

        // Parse the number between prefix and extension
        int index = atoi(fno.fname + prefix_len);
        if (index > max_index)
            max_index = index;
    }

    f_closedir(&dir);
    snprintf(out, out_size, "%s%d.%s", prefix, max_index + 1, ext);
    return true;
}

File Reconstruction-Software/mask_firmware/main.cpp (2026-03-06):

/*==========================================================================
 * FILE_NAME:   main.cpp (Codebook Generator)
 * 
 * PURPOSE:     Generates the complete 64x64 Walsh-Hadamard codebook (4096 masks) 
 *              using the shared hardware library. Saves the output as a flat 
 *              binary file (16 MB) to be verified against the MATLAB reference 
 *              model. This ensures the C++ hardware math is 100% accurate 
 *              before flashing it to the Pi Pico 2.
 * 
 * AUTHOR:      Cole Mckay (cdmckay1@ualberta.ca)
 * DATE:        March 5, 2026
 * VERSION:     1.0
 *
 * DEPENDENCIES: WalshMaskGenerator.h, WalshMaskGenerator.cpp
 *==========================================================================*/

#include <iostream>
#include <fstream>
#include "WalshMaskGenerator.h"

int main() {
    int img_width = 64;
    int img_height = 64;
    int total_masks = img_width * img_height;
    int pixels_per_mask = img_width * img_height;

    // Open a binary file for writing
    std::ofstream outfile("cpp_codebook.bin", std::ios::binary);
    if (!outfile) {
        std::cerr << "Failed to open file for writing." << std::endl;
        return 1;
    }

    std::cout << "Generating 4096 masks..." << std::endl;

    // Allocate a buffer for a single mask (4,096 bytes)
    uint8_t mask_buffer[4096];

    for (int index = 0; index < total_masks; ++index) {
        
        // 1. Generate the mask using the external hardware function
        generate_walsh_mask(index, img_width, img_height, mask_buffer);

        // 2. Write the entire 4096-byte buffer to the file in one shot
        outfile.write(reinterpret_cast<const char*>(mask_buffer), pixels_per_mask);
        
    }

    outfile.close();
    std::cout << "Codebook saved to cpp_codebook.bin" << std::endl;
    return 0;
}

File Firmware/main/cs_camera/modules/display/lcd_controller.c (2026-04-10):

#include "lcd_controller.h"
#include "pico/stdlib.h"
#include "pico/st7789.h"

static const struct st7789_config lcd_config = {
    .spi      = PICO_DEFAULT_SPI_INSTANCE(),
    .gpio_din = PICO_DEFAULT_SPI_TX_PIN, // GP19
    .gpio_clk = PICO_DEFAULT_SPI_SCK_PIN, // GP18
    .gpio_cs  = -1,
    .gpio_dc  = 21,
    .gpio_rst = 20,
    .gpio_bl  = 22,
};

static const int lcd_width = LCD_WIDTH;
static const int lcd_height = LCD_HEIGHT;

#define COLOR_BLACK 0x0000
#define COLOR_WHITE 0xFFFF

bool display_init(void) {
    st7789_init(&lcd_config, lcd_width, lcd_height);
    return true;
}

void display_fill(uint16_t rgb565) {
    st7789_fill(rgb565);
}

void display_show_mask(const uint8_t *mask, int mask_width, int mask_height) {
    static uint16_t framebuf[LCD_WIDTH * LCD_HEIGHT];

    const int scale = 3;
    const int render_width = mask_width * scale;    // 64 * 3 = 192
    const int render_height = mask_height * scale;  // 64 * 3 = 192

    const int x_offset = (LCD_WIDTH - render_width) / 2;   // 24
    const int y_offset = (LCD_HEIGHT - render_height) / 2; // 24

    // Fill entire screen black first
    for (int i = 0; i < LCD_WIDTH * LCD_HEIGHT; i++) {
        framebuf[i] = COLOR_BLACK;
    }

    // Draw each mask pixel as a 3x3 block
    for (int y = 0; y < mask_height; y++) {
        for (int x = 0; x < mask_width; x++) {
            uint16_t color = mask[y * mask_width + x] ? COLOR_WHITE : COLOR_BLACK;

            int lcd_x_start = x_offset + x * scale;
            int lcd_y_start = y_offset + y * scale;

            for (int dy = 0; dy < scale; dy++) {
                for (int dx = 0; dx < scale; dx++) {
                    int lcd_x = lcd_x_start + dx;
                    int lcd_y = lcd_y_start + dy;
                    framebuf[lcd_y * LCD_WIDTH + lcd_x] = color;
                }
            }
        }
    }

    st7789_set_cursor(0, 0);
    st7789_write(framebuf, sizeof(framebuf));
}

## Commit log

2026-01-26 Add .gitkeep files to track empty directories for Firmware, Image_reconstruction, data, docs, hardware, and tests
2026-02-02 Add Raspberry Pi Pico pinout diagram to documentation
2026-02-18 added schematic v1.0
2026-02-22 Refactored the code for sd card tested and it works RTC was giving me errors so I had to disable it in the ffconf.h file this only for the sd card stuff
    [cs_camera.c, hw_config.c]
2026-02-26 added a physical wiring diagram
2026-02-26 updated schematic based on wiring diagram
2026-03-04 button code added and tested
2026-03-04 added sensor reading code and sd card buffer data saving
2026-03-11 added reconstruction framework
2026-03-11 added reconstruction framework (redo)
2026-03-12 added file functionality to app
    d
    [Lens D-Cx Dia38mm FL50mm.f3d, SD Card Reader (Assembly).f3z, camera_data_export.csv]
2026-03-17 fixed pinouts to match schematic and hardware
    [hw_config.c, lcd_controller.c]
2026-03-18 added button, LEDs, and added guaranteed indices
2026-03-19 added test for sensor data reconstruction
    [camera_data_export.csv, sensor_data.csv]
2026-03-25 changes to emulator and scripts
    [camera_data_export.csv]
2026-03-25 added extensive feature suit to matlab app and restructured sw folder
    [camera_data_export.csv, sensor_data.csv]
2026-04-08 Large feature change for Reconstruction software
    [camera_data_export.csv]
